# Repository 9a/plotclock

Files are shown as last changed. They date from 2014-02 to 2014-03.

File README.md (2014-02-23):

plotclock
=========

plotclock

a clock that plots time

What you need
-------------
* Lasercutter or 3D Printer

* one Arduino (e.g. uno)

* three RC-Servos Mini (e.g. Tower Pro 9g)

* one whiteboard marker, dry eerasable (e.g. WB SL DRYWIPE MARKER)

* Screws, nuts, washers M3 and a tap for cutting M3.

Assembly
--------

See: http://www.thingiverse.com/thing:248009/#instructions

--

this actually is my first git project, so merging, forks etc. is still new to me and could take some time

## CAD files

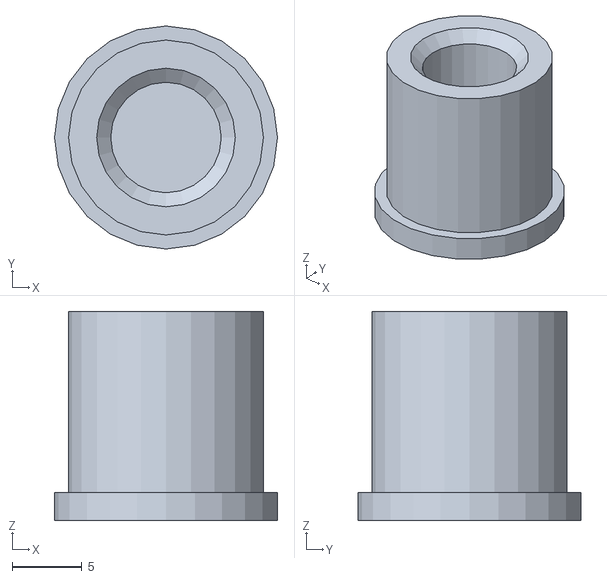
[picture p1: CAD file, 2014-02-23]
swee.stl
16.0 x 16.0 x 15.0

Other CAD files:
plotclock_SUP7.skp

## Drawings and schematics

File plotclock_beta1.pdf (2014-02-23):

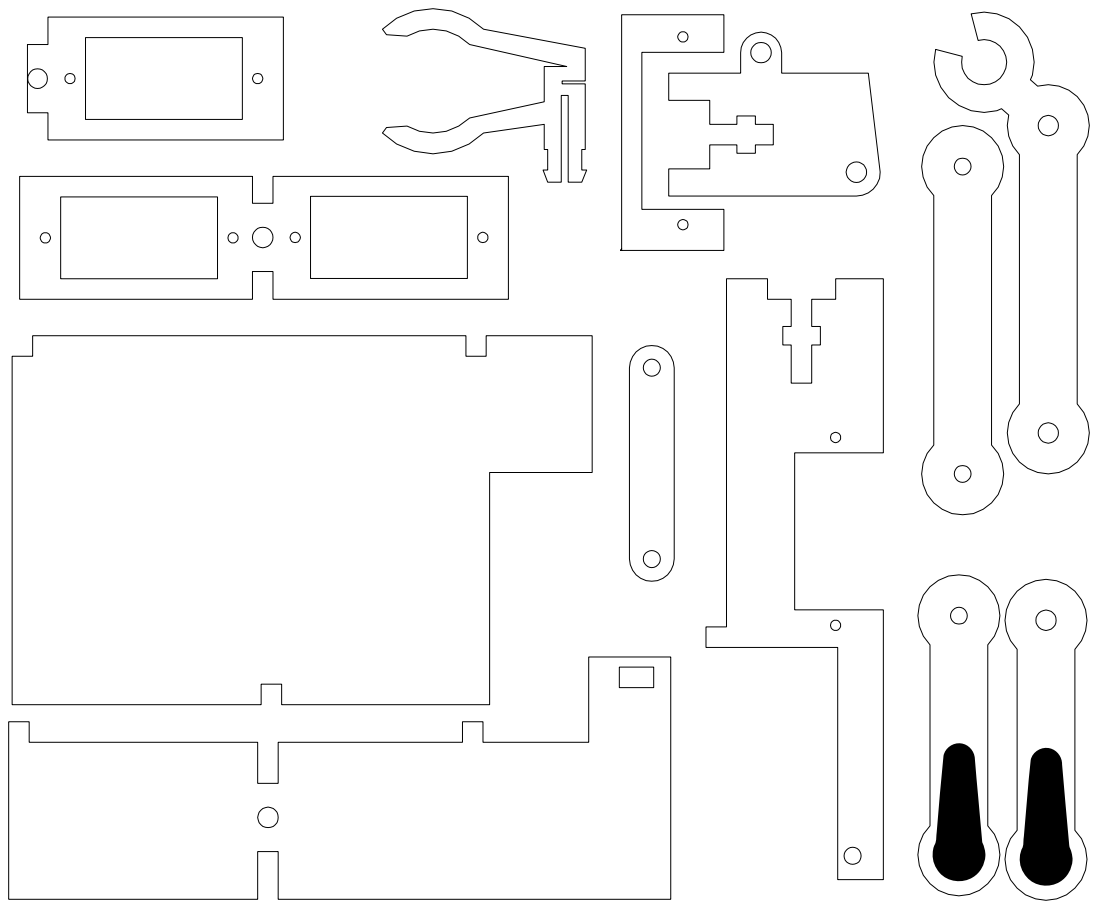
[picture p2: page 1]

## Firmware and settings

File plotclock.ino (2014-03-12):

// Plotclock
// cc - by Johannes Heberlein 2014
// v 1.02
// thingiverse.com/joo   wiki.fablab-nuernberg.de
// units: mm; microseconds; radians
// origin: bottom left of drawing surface
// time library see http://playground.arduino.cc/Code/time 
// RTC  library see http://playground.arduino.cc/Code/time 
//               or http://www.pjrc.com/teensy/td_libs_DS1307RTC.html  
// Change log:
// 1.01  Release by joo at https://github.com/9a/plotclock
// 1.02  Additional features implemented by Dave:
//       - added ability to calibrate servofaktor seperately for left and right servos
//       - added code to support DS1307, DS1337 and DS3231 real time clock chips
//       - see http://www.pjrc.com/teensy/td_libs_DS1307RTC.html for how to hook up the real time clock 

// delete or mark the next line as comment if you don't need these
#define CALIBRATION      // enable calibration mode
//#define REALTIMECLOCK    // enable real time clock

// When in calibration mode, adjust the following factor until the servos move exactly 90 degrees
#define SERVOFAKTORLEFT 650
#define SERVOFAKTORRIGHT 650

// Zero-position of left and right servo
// When in calibration mode, adjust the NULL-values so that the servo arms are at all times parallel
// either to the X or Y axis
#define SERVOLEFTNULL 2250
#define SERVORIGHTNULL 920

#define SERVOPINLIFT  2
#define SERVOPINLEFT  3
#define SERVOPINRIGHT 4

// lift positions of lifting servo
#define LIFT0 1080 // on drawing surface
#define LIFT1 925  // between numbers
#define LIFT2 725  // going towards sweeper

// speed of liftimg arm, higher is slower
#define LIFTSPEED 1500

// length of arms
#define L1 35
#define L2 55.1
#define L3 13.2

// origin points of left and right servo 
#define O1X 22
#define O1Y -25
#define O2X 47
#define O2Y -25

#include <Time.h> // see http://playground.arduino.cc/Code/time 
#include <Servo.h>

#ifdef REALTIMECLOCK
// for instructions on how to hook up a real time clock,
// see here -> http://www.pjrc.com/teensy/td_libs_DS1307RTC.html
// DS1307RTC works with the DS1307, DS1337 and DS3231 real time clock chips.
// Please run the SetTime example to initialize the time on new RTC chips and begin running.

  #include <Wire.h>
  #include <DS1307RTC.h> // see http://playground.arduino.cc/Code/time    
#endif

int servoLift = 1500;

Servo servo1;  // 
Servo servo2;  // 
Servo servo3;  // 

volatile double lastX = 75;
volatile double lastY = 47.5;

int last_min = 0;

void setup() 
{ 
#ifdef REALTIMECLOCK
  Serial.begin(9600);
  //while (!Serial) { ; } // wait for serial port to connect. Needed for Leonardo only

  // Set current time only the first to values, hh,mm are needed  
  tmElements_t tm;
  if (RTC.read(tm)) 
  {
    setTime(tm.Hour,tm.Minute,tm.Second,tm.Day,tm.Month,tm.Year);
    Serial.println("DS1307 time is set OK.");
  } 
  else 
  {
    if (RTC.chipPresent())
    {
      Serial.println("DS1307 is stopped.  Please run the SetTime example to initialize the time and begin running.");
    } 
    else 
    {
      Serial.println("DS1307 read error!  Please check the circuitry.");
    } 
    // Set current time only the first to values, hh,mm are needed
    setTime(19,38,0,0,0,0);
  }
#else  
  // Set current time only the first to values, hh,mm are needed
  setTime(19,38,0,0,0,0);
#endif

  drawTo(75.2, 47);
  lift(0);
  servo1.attach(SERVOPINLIFT);  //  lifting servo
  servo2.attach(SERVOPINLEFT);  //  left servo
  servo3.attach(SERVOPINRIGHT);  //  right servo
  delay(1000);

} 

void loop() 
{ 

#ifdef CALIBRATION

  // Servohorns will have 90° between movements, parallel to x and y axis
  drawTo(-3, 29.2);
  delay(500);
  drawTo(74.1, 28);
  delay(500);

#else 


  int i = 0;
  if (last_min != minute()) {

    if (!servo1.attached()) servo1.attach(SERVOPINLIFT);
    if (!servo2.attached()) servo2.attach(SERVOPINLEFT);
    if (!servo3.attached()) servo3.attach(SERVOPINRIGHT);

    lift(0);

    hour();
    while ((i+1)*10 <= hour())
    {
      i++;
    }

    number(3, 3, 111, 1);
    number(5, 25, i, 0.9);
    number(19, 25, (hour()-i*10), 0.9);
    number(28, 25, 11, 0.9);

    i=0;
    while ((i+1)*10 <= minute())
    {
      i++;
    }
    number(34, 25, i, 0.9);
    number(48, 25, (minute()-i*10), 0.9);
    lift(2);
    drawTo(74.2, 47.5);
    lift(1);
    last_min = minute();

    servo1.detach();
    servo2.detach();
    servo3.detach();
  }

#endif

} 

// Writing numeral with bx by being the bottom left originpoint. Scale 1 equals a 20 mm high font.
// The structure follows this principle: move to first startpoint of the numeral, lift down, draw numeral, lift up
void number(float bx, float by, int num, float scale) {

  switch (num) {

  case 0:
    drawTo(bx + 12 * scale, by + 6 * scale);
    lift(0);
    bogenGZS(bx + 7 * scale, by + 10 * scale, 10 * scale, -0.8, 6.7, 0.5);
    lift(1);
    break;
  case 1:

    drawTo(bx + 3 * scale, by + 15 * scale);
    lift(0);
    drawTo(bx + 10 * scale, by + 20 * scale);
    drawTo(bx + 10 * scale, by + 0 * scale);
    lift(1);
    break;
  case 2:
    drawTo(bx + 2 * scale, by + 12 * scale);
    lift(0);
    bogenUZS(bx + 8 * scale, by + 14 * scale, 6 * scale, 3, -0.8, 1);
    drawTo(bx + 1 * scale, by + 0 * scale);
    drawTo(bx + 12 * scale, by + 0 * scale);
    lift(1);
    break;
  case 3:
    drawTo(bx + 2 * scale, by + 17 * scale);
    lift(0);
    bogenUZS(bx + 5 * scale, by + 15 * scale, 5 * scale, 3, -2, 1);
    bogenUZS(bx + 5 * scale, by + 5 * scale, 5 * scale, 1.57, -3, 1);
    lift(1);
    break;
  case 4:
    drawTo(bx + 10 * scale, by + 0 * scale);
    lift(0);
    drawTo(bx + 10 * scale, by + 20 * scale);
    drawTo(bx + 2 * scale, by + 6 * scale);
    drawTo(bx + 12 * scale, by + 6 * scale);
    lift(1);
    break;
  case 5:
    drawTo(bx + 2 * scale, by + 5 * scale);
    lift(0);
    bogenGZS(bx + 5 * scale, by + 6 * scale, 6 * scale, -2.5, 2, 1);
    drawTo(bx + 5 * scale, by + 20 * scale);
    drawTo(bx + 12 * scale, by + 20 * scale);
    lift(1);
    break;
  case 6:
    drawTo(bx + 2 * scale, by + 10 * scale);
    lift(0);
    bogenUZS(bx + 7 * scale, by + 6 * scale, 6 * scale, 2, -4.4, 1);
    drawTo(bx + 11 * scale, by + 20 * scale);
    lift(1);
    break;
  case 7:
    drawTo(bx + 2 * scale, by + 20 * scale);
    lift(0);
    drawTo(bx + 12 * scale, by + 20 * scale);
    drawTo(bx + 2 * scale, by + 0);
    lift(1);
    break;
  case 8:
    drawTo(bx + 5 * scale, by + 10 * scale);
    lift(0);
    bogenUZS(bx + 5 * scale, by + 15 * scale, 5 * scale, 4.7, -1.6, 1);
    bogenGZS(bx + 5 * scale, by + 5 * scale, 5 * scale, -4.7, 2, 1);
    lift(1);
    break;

  case 9:
    drawTo(bx + 9 * scale, by + 11 * scale);
    lift(0);
    bogenUZS(bx + 7 * scale, by + 15 * scale, 5 * scale, 4, -0.5, 1);
    drawTo(bx + 5 * scale, by + 0);
    lift(1);
    break;

  case 111:

    lift(0);
    drawTo(70, 46);
    drawTo(65, 43);

    drawTo(65, 49);
    drawTo(5, 49);
    drawTo(5, 45);
    drawTo(65, 45);
    drawTo(65, 40);

    drawTo(5, 40);
    drawTo(5, 35);
    drawTo(65, 35);
    drawTo(65, 30);

    drawTo(5, 30);
    drawTo(5, 25);
    drawTo(65, 25);
    drawTo(65, 20);

    drawTo(5, 20);
    drawTo(60, 44);

    drawTo(75.2, 47);
    lift(2);

    break;

  case 11:
    drawTo(bx + 5 * scale, by + 15 * scale);
    lift(0);
    bogenGZS(bx + 5 * scale, by + 15 * scale, 0.1 * scale, 1, -1, 1);
    lift(1);
    drawTo(bx + 5 * scale, by + 5 * scale);
    lift(0);
    bogenGZS(bx + 5 * scale, by + 5 * scale, 0.1 * scale, 1, -1, 1);
    lift(1);
    break;

  }
}



void lift(char lift) {
  switch (lift) {
    // room to optimize  !

  case 0: //850

      if (servoLift >= LIFT0) {
      while (servoLift >= LIFT0) 
      {
        servoLift--;
        servo1.writeMicroseconds(servoLift);				
        delayMicroseconds(LIFTSPEED);
      }
    } 
    else {
      while (servoLift <= LIFT0) {
        servoLift++;
        servo1.writeMicroseconds(servoLift);
        delayMicroseconds(LIFTSPEED);

      }

    }

    break;

  case 1: //150

    if (servoLift >= LIFT1) {
      while (servoLift >= LIFT1) {
        servoLift--;
        servo1.writeMicroseconds(servoLift);
        delayMicroseconds(LIFTSPEED);

      }
    } 
    else {
      while (servoLift <= LIFT1) {
        servoLift++;
        servo1.writeMicroseconds(servoLift);
        delayMicroseconds(LIFTSPEED);
      }

    }

    break;

  case 2:

    if (servoLift >= LIFT2) {
      while (servoLift >= LIFT2) {
        servoLift--;
        servo1.writeMicroseconds(servoLift);
        delayMicroseconds(LIFTSPEED);
      }
    } 
    else {
      while (servoLift <= LIFT2) {
        servoLift++;
        servo1.writeMicroseconds(servoLift);				
        delayMicroseconds(LIFTSPEED);
      }
    }
    break;
  }
}


void bogenUZS(float bx, float by, float radius, int start, int ende, float sqee) {
  float inkr = -0.05;
  float count = 0;

  do {
    drawTo(sqee * radius * cos(start + count) + bx,
    radius * sin(start + count) + by);
    count += inkr;
  } 
  while ((start + count) > ende);

}

void bogenGZS(float bx, float by, float radius, int start, int ende, float sqee) {
  float inkr = 0.05;
  float count = 0;

  do {
    drawTo(sqee * radius * cos(start + count) + bx,
    radius * sin(start + count) + by);
    count += inkr;
  } 
  while ((start + count) <= ende);
}


void drawTo(double pX, double pY) {
  double dx, dy, c;
  int i;

  // dx dy of new point
  dx = pX - lastX;
  dy = pY - lastY;
  //path lenght in mm, times 4 equals 4 steps per mm
  c = floor(4 * sqrt(dx * dx + dy * dy));

  if (c < 1) c = 1;

  for (i = 0; i <= c; i++) {
    // draw line point by point
    set_XY(lastX + (i * dx / c), lastY + (i * dy / c));

  }

  lastX = pX;
  lastY = pY;
}

double return_angle(double a, double b, double c) {
  // cosine rule for angle between c and a
  return acos((a * a + c * c - b * b) / (2 * a * c));
}

void set_XY(double Tx, double Ty) 
{
  delay(1);
  double dx, dy, c, a1, a2, Hx, Hy;

  // calculate triangle between pen, servoLeft and arm joint
  // cartesian dx/dy
  dx = Tx - O1X;
  dy = Ty - O1Y;

  // polar lemgth (c) and angle (a1)
  c = sqrt(dx * dx + dy * dy); // 
  a1 = atan2(dy, dx); //
  a2 = return_angle(L1, L2, c);

  servo2.writeMicroseconds(floor(((a2 + a1 - M_PI) * SERVOFAKTORLEFT) + SERVOLEFTNULL));

  // calculate joinr arm point for triangle of the right servo arm
  a2 = return_angle(L2, L1, c);
  Hx = Tx + L3 * cos((a1 - a2 + 0.621) + M_PI); //36,5°
  Hy = Ty + L3 * sin((a1 - a2 + 0.621) + M_PI);

  // calculate triangle between pen joint, servoRight and arm joint
  dx = Hx - O2X;
  dy = Hy - O2Y;

  c = sqrt(dx * dx + dy * dy);
  a1 = atan2(dy, dx);
  a2 = return_angle(L1, (L2 - L3), c);

  servo3.writeMicroseconds(floor(((a1 - a2) * SERVOFAKTORRIGHT) + SERVORIGHTNULL));

}

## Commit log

2014-02-12 Working arduino Version
2014-02-18 Added calibration routine, clean up
2014-02-21 Added skp, pdf, stl files. Added an english translation of the instructions found on wiki.fablab-nuernberg.de/w/Ding:Plotclock#Zusammenbau
    [plotclock_SUP7.skp, swee.stl]
2014-02-26 Plotclock V1.02
    V1.02 Additional features implemented by Dave:
    - added ability to calibrate servofaktor seperately for left and right
    servos
    - added code to support DS1307, DS1337 and DS3231 real time clock chips
